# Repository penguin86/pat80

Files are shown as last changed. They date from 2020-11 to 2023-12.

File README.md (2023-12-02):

# Pat80

Pat80 Home Computer Logo

Pat80 Home Computer is an attempt to develop the simplest possible Zilog Z80 based computer in 2021.

## Hardware
Instead of being another single board computer, Pat80 focuses on modularity:
- The Core board contains Z80 CPU, 32k ram, 32k rom, memory and I/O decoding logic
- The Backplane is a stupid I/O bus board with no active components, 1 socket for the Core board and 8 sockets for I/O boards
- Each I/O board must implement tri-state and go to high impedance according to its EN pin to avoid bus contention
- The Power Supply module contains a 7805-based linear power supply capable of delivering 1A @5v for the core and I/O boards

Here is a picture of the early stages of development:

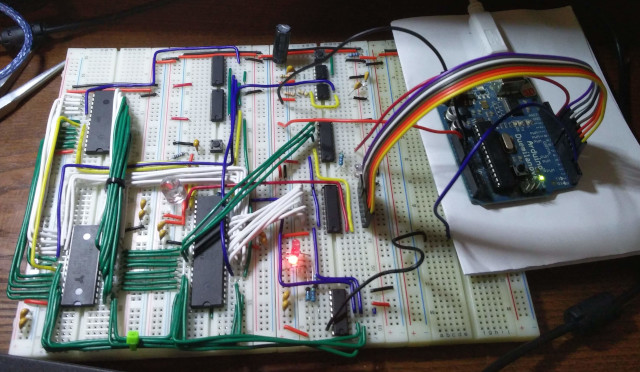
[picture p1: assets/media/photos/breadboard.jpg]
Pat80 Breadboard prototype


### I/O Boards

#### Parallel terminal interface
A parallel terminal based on Arduino is used for development purposes and will be replaced by an UART card.

#### Keyboard controller
Pat80 features a blue-switches mechanical matrix keyboard, seen by the system as a memory area in I/O space. The keyboard doesn't use interrupts and is polled by the OS.

#### Video controller
The monochrome 368x248 pixels video output is software-generated by an ATMega 1284 MCU. The timings are generated by the MCU's 16 bit internal timer and the vertical sync time is used to update the framebuffer.

## Software
The OS is a simple Memory Monitor. It can show memory content in hex and ascii with the typical hex editor tabular view.
Programs can be loaded from the keyboard, writing Z80 opcodes and data in hex. The program can be executed from any ram position and the Memory Monitor can be brought to screen in any moment issuing an INT signal (the Z80 INT pin should be connected to a button with pull-up resistor).
There is an experimental and unfinished quick load function using a python terminal to load a binary file directly to memory and execute it.

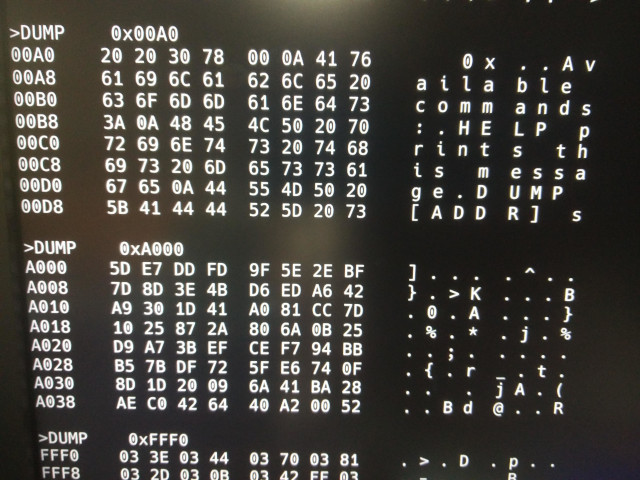
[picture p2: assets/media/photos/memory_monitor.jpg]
Pat80 Memory Monitor


## Emulator
The pat80 memory monitor (the os) can be run in a z80 emulator. This repository contains an emulator as submodule, already set up to run the os.
To try it, head to `pat80-computer/software/z80-assembly/os/Makefile` and run `make run` to build the rom from assembly and start the emulator. You will see some windows showing the emulated computer's memory and register status and the pat80 memory monitor prompt.

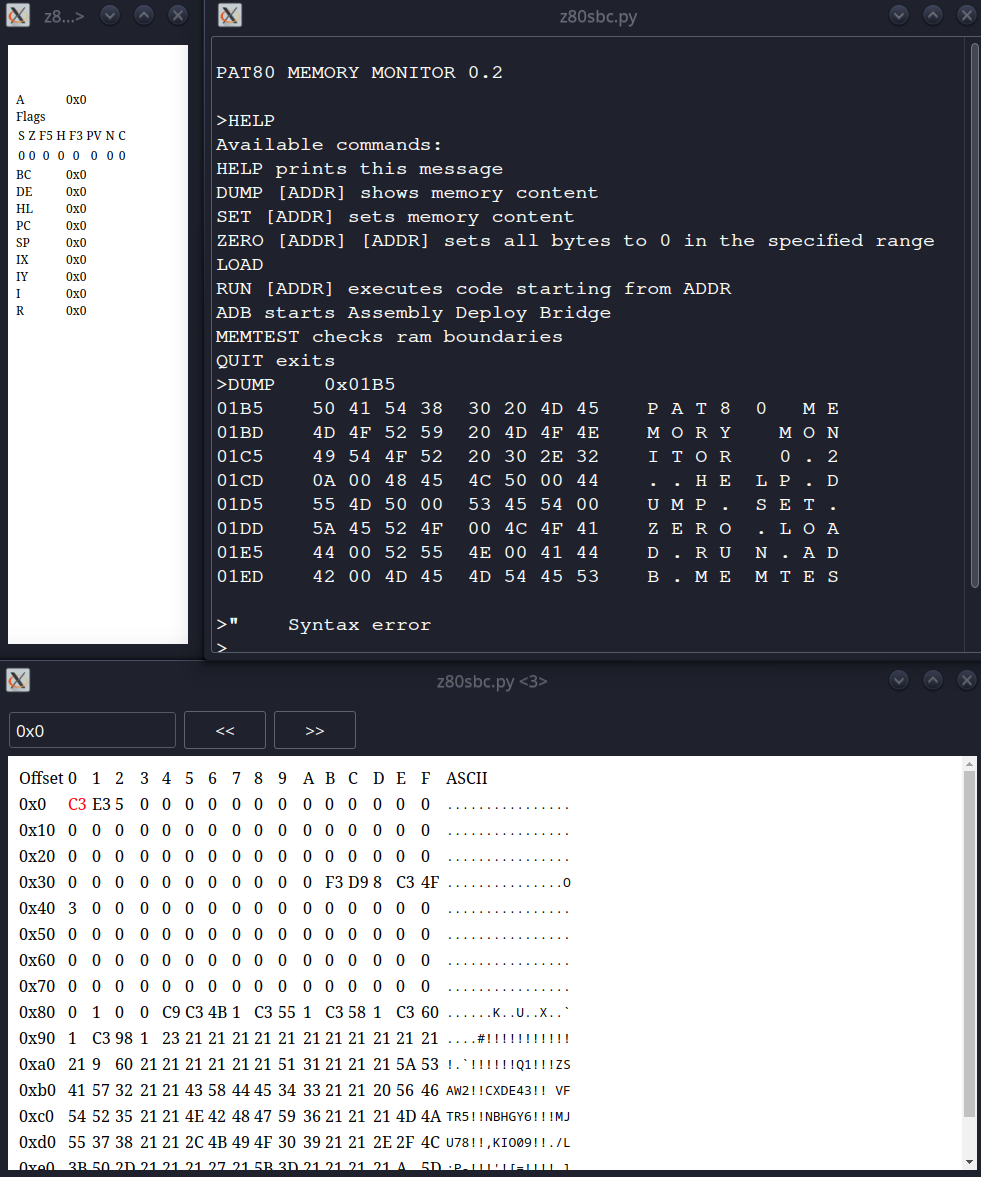
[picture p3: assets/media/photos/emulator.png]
Emulator running Memory Monitor


## Status
The project is heavily work in progress.

### Working
- Core board
- Sound board
- Arduino parallel terminal with its own Python companion script (or any UART terminal)

The only fully working configuration as now is the Core board with two devices hooked to its I/O bus: the Arduino Parallel Terminal (see `pat80-io-devices/parallel-terminal` and `pat80-computer/software/z80-assembly/os/drivers/arduino_terminal.asm`) and the SN76489 sound chip (see `pat80-computer/software/z80-assembly/os/drivers/hd44780.asm`)

### Partially working
The keyboard is only partially tested, as it's not completed.

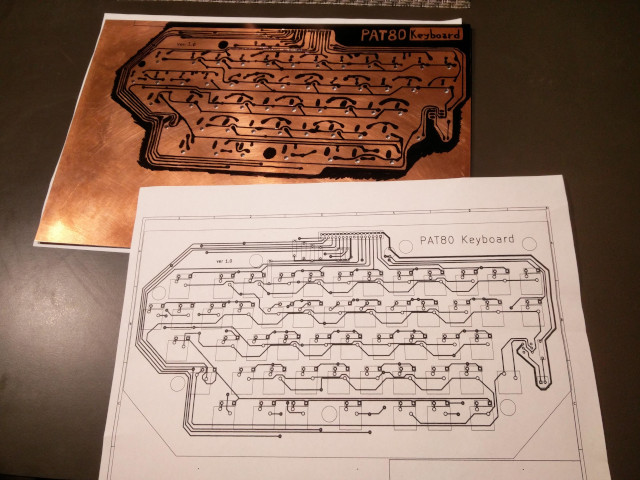
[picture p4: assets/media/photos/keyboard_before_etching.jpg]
Pat80 keyboard pcb


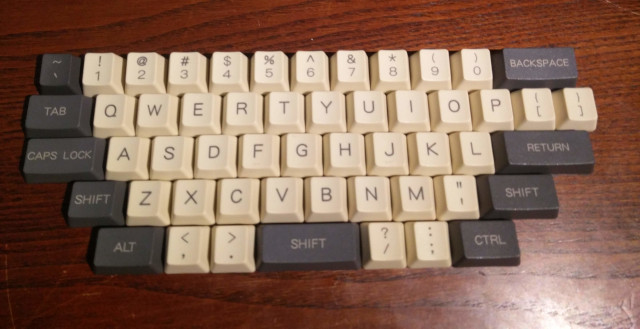
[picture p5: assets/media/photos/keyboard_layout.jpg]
Pat80 keyboard layout


The composite video card is partially working, but has some nasty bugs on text cursor positioning and the graphics mode is not yet implemented (the only way to output graphics ATM is to place the bitmap in the MCU flash and load it to VRAM manually).

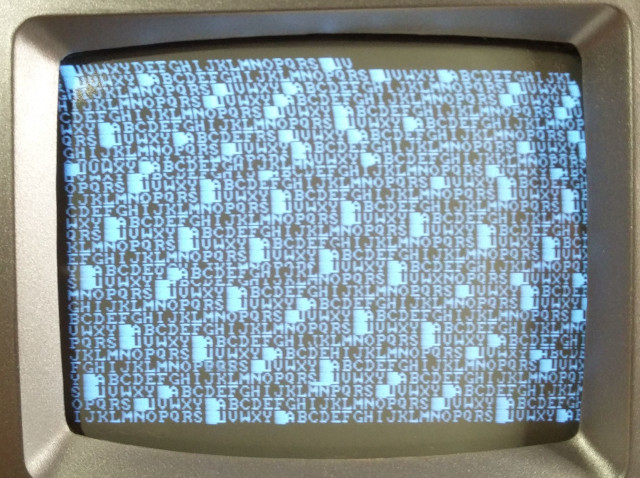
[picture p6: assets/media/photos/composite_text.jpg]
Pat80 composite monitor text mode


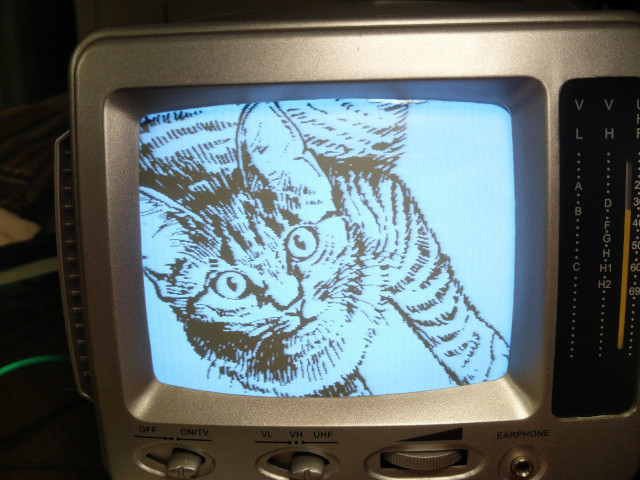
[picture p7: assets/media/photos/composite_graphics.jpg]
Pat80 composite monitor graphics mode


For the moment, better to stick with the Arduino Parallel Terminal.

### Not working
All the rest

## License
All the project is under GPL v3 license

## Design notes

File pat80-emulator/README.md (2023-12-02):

# PAT80 Emulator
This folder contains a submodule (you should fetch it if you need to run the os in an emulator).

Uses cburbridge's Z80 emulator written in python. It opens some windows showing the emulated computer's memory map, the cpu registers state and parallel terminal to interact with the os.

## Usage
To run the os in the emulator, head to `pat80-computer/software/z80-assembly/os/Makefile` and run `make run` to build the rom from assembly and start the emulator.

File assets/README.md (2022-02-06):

# Assets
This folder contains all the media and text assets for presenting Pat80 to the web, print and other media

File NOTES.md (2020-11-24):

# Software utilizzato
Compilatore assembly: z80asm (da repo debian)
Compilatore c: sdcc (da repo debian)
Eeprom flash: minipro (da https://gitlab.com/DavidGriffith/minipro/)
Disegnatore schemi logici: logisim (jar da sourceforge)
    Per usarlo su hdpi: `java -Dsun.java2d.uiScale=2 -jar logisim-generic-2.7.1.jar`
Disegnatore circuiti: fritzing (da repo debian)

# Assembly
## Deploy
### Compilare assembly:
`z80asm -i hd44780_lcd_test_procedure.asm -o rom.bin`
### Portare binario alla dimensione dell eeprom:
`dd if=/dev/zero of=rom.bin bs=1 count=0 seek=8192`
### Scrivere su EEPROM:
`minipro -w rom.bin -p "AT28C64B"`
### Leggere EEPROM:
`minipro -r rom_read.bin -p "AT28C64B"`
## Istruzioni
### Dichiarare una variabile:
Usare EQU per assegnare una posizione di memoria nota (nella RAM) al nome variabile.
```
myVar: EQU 0x800F   ; init variable
ld hl, "A"          ; load value into register
ld (myVar), hl      ; copy value into variable
```
NB: Se il programma si blocca, verificare che la variabile non sia stata dichiarata in una parte non scrivibile della memoria (ROM)
### Accedere ad una variabile
Modificarne il valore (nell'esempio: incrementarla di 1)
```
ld a, (myVar)
inc a
ld (myVar), a
```
Passarne il puntatore ad una funzione:
```
ld bc, myVar
call lcd_print
```
### Segmentation fault
Controllare che non si stia puntando ad un registro con le parentesi:
`ld (ix), a`

# C
## Deploy
### Compilare c:
`sdcc -mz80 test.c`

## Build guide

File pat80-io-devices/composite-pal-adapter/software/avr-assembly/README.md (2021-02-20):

# Atmega Microcontroller
## Build ASM code
`avra filename.asm` (generates *filename.hex*)

## Flash
### Rom
`minipro -w filename.hex -p ATMEGA1284`
### Fuses
Read fuses: `minipro -r -c config -p ATMEGA1284` (`-r -c config` means read configuration (fuses))
Fuses must be written all together, so read the current values, edit the generated file and write it.
The meaning of every bis is in the conf file.
Write fuses: `minipro -w fuses.conf -c config -p ATMEGA1284`

# Generate test images
Using GIMP, Image -> Mode -> Indexed, select 2 colors and Posterize.
Invert the image colors.
Save as .xbm file. Oper with a *text editor*, you will find an array of byte-packed pixels (every byte represents 8 pixels).
Copy and paste on an ASM file.

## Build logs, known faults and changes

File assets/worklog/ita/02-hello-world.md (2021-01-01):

"Roma non è stata costruita in un giorno".
Cominceremo dalle basi. E la base di un computer è proprio il processore.
Il contenuto della scatolina vista nello scorso post è lo Zilog Z80, un processore progettato da Federico Faggin nella prima metà degli anni 70, ed utilizzato poi in innumerevoli computer e console, fino agli anni 90 (eh si, a quei tempi non usciva un processore l'anno...).
Questa CPU è ancora in produzione, sebbene "aggiornata" facendo uso della tecnologia CMOS, molto più efficiente e parca nei consumi. Il modello in mio possesso può essere clockato fino ad 8Mhz, ma se ne trovano modelli fino a 20Mhz! All'epoca una frequenza comune per questo processore era intorno ai 3Mhz (spesso 3,57 per utilizzare un solo cristallo sia per la CPU che per la [generazione di colore per il video](https://en.wikipedia.org/wiki/NTSC#Color_encoding) ).
Oggi, però, la faremo girare moooooolto più lenta.

Da dove cominciare? Per saperlo, bisogna chiederci quale sia il comportamento atteso di un processore. Non è la sede per una spiegazione approfondita, ma basti sapere che il processore (anche i più moderni) non fa altro che eseguire delle istruzioni. Una istruzione è un byte (o se preferite un numero da 0 a 255) che dice al processore cosa fare.
Questo viene ripetuto all'infinito, in un ciclo composto da tre fasi:
- Fetch (ottiene l'istruzione da eseguire dalla memoria)
- Decode (interpreta l'istruzione)
- Execute (la esegue)
Per la nostra prima prova abbiamo bisogno di sapere anche come funziona la memoria.
Ogni memoria (ROM, RAM, Flash...) è composta da una serie di posizioni che possono contenere dei valori. Si accede al contenuto di una posizione in base al suo indirizzo.
Quando il processore viene avviato, non fa altro che cominciare dalla prima posizione di memoria (0), leggere il contenuto (Fetch), capire cosa significa (Decode), eseguirlo (Execute) e passare alla successiva posizione di memoria (1), dove ricomincia da capo.
Ovviamente alcune istruzioni possono modificare questo flusso, ad esempio l'istruzione JP (Jump) dice al processore "Non andare a prendere la prossima posizione di memoria, ma salta alla posizione X".
Per questo motivo noi siamo interessati all'istruzione NOP, (No OPeration): questa istruzione non fa assolutamente nulla. Spreca un ciclo di cpu senza toccare nulla, per cui il processore andrà a cercare l'istruzione successiva nella posizione di memoria successiva.
Ci aspettiamo quindi di vedere i seguenti accessi alla memoria (a destra il valore binario):
0   00000000 00000000
1   00000000 00000001
2   00000000 00000010
3   00000000 00000011
4   00000000 00000100
5   00000000 00000101
etc etc ...

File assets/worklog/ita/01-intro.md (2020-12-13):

È l'inizio degli anni 80. Nelle sale spopolano i Ghostbusters, La Storia Infinita ed E.T. Per i Goonies e Ritorno al futuro bisogna aspettare ancora un po'. La radio suona Girls Just Want To Have Fun di Cyndi Lauper e gli Iron Maiden rilasciano Aces High. Nelle case degli italiani cominciano a comparire i primi Commodore 64, collegati all'onnipresente TV color in sala, magari litigandosi l'unica entrata RF del televisore con un fiammante VHS. Per il NES, invece, bisognerà aspettare ancora un bel po'.

È cominciata la rivoluzione degli Home Computers. I calcolatori non sono più costosissimi ed ingombranti apparecchi riservati ad istituzioni e grosse aziende, ma arrivano nelle case di tutti, in formati compatti e convenienti, a cifre inferiori al mezzo milione di lire. Il software è distribuito prevalentemente su audiocassetta o come listati BASIC da inserire attraverso la tastiera, comprando in edicola i magazines per gli appassionati di home computers.

Solo pochi anni prima sarebbe stato impossibile, per gran parte delle persone, procurarsi un computer, tanto che gli appassionati col pallino dell'elettronica tentavano di costruirsene uno. Gli "homebrew computers" (computer "fatti in casa") sono i veri responsabili dell'inizio di questa rivoluzione, con tutta la letteratura collegata, come i capolavori Build your own Z80 computer di Steve Ciarcia, The Cheap Video cookbook di Don Lancaster o la bibbia di programmazione assembly Programming the Z80 di Rodnay Zaks.

Ho sempre desiderato poter vivere sulla mia pelle la rivoluzione informatica di quegli anni, ma non ne ho avuto la possibilità: non ero ancora nato, e non si può tornare indietro nel tempo.

... oppure sì? Magari con un po' di fantasia! Immaginiamo di essere un appassionato di elettronica desideroso di avere un computer tutto suo. Immaginiamo di riuscire a procurarci un processore. Magari lo Zilog Z80, progettato dall'italiano Federico Faggin e rilasciato nel '76, superiore in molti aspetti al diffusissimo MOS 6502 che dava vita all'Apple II.

Allora, avete voglia di seguirmi in questo viaggio di fantasia che mi porterà a progettare e costruire il:

[LOGO PAT80 COLOR]

L'idea è quella di progettare e costruire un computer da zero, come avrebbe fatto un appassionato a cavallo tra gli anni 70 ed 80. Ispirarmi alle soluzioni esistenti, ma mai copiare e mai inseguire la compatibilità con qualche sistema preesistente. Questo comporterà che io, che non ho mai toccato l'Assembly, scriva un sistema operativo da zero. Probabilità di successo dell'intera impresa: 0%. Ma il calabrone, che non sa di non poter volare, vola lo stesso :"D

Qui Babbo Natale è passato in anticipo, ed ha portato un pacco pieno di... integrati! Ma cosa conterrà la scatolina in cima? Ha 40 pin, ha fatto la storia dell'informatica ma viene prodotto tutt'ora! Molti di voi avranno intuito chi è... ma per gli altri, dovrete aspettare una settimana! 😛

Bio:

Io sono Daniele Verducci, classe '86, professione sviluppatore Android. Conosco Java, Kotlin, linguaggi di alto livello. Per me C o GoLang sono linguaggi di basso livello. L'assembly è aramaico. Elettronicamente, so cos'è un Arduino e ho seguito il corso di elettronica di Andre LaMothe. Sono quasi completamente fuori dalla mia area di competenza, quindi abbiate pazienza se gli aggiornamenti del progetto non saranno frequenti o se rimarrò incagliato, per periodi più o meno lunghi, su qualche problema prima di capire come risolverlo. L'idea è proprio di imparare qualcosa di nuovo, e di farlo insieme!

Sono un appassionato dell'open source, per cui, anche se la macchina non sarà mai in grado di far girare Linux, gli schemi ed i sorgenti del sistema operativo scritto ad hoc saranno rilasciati tutti con licenza GPL v3.

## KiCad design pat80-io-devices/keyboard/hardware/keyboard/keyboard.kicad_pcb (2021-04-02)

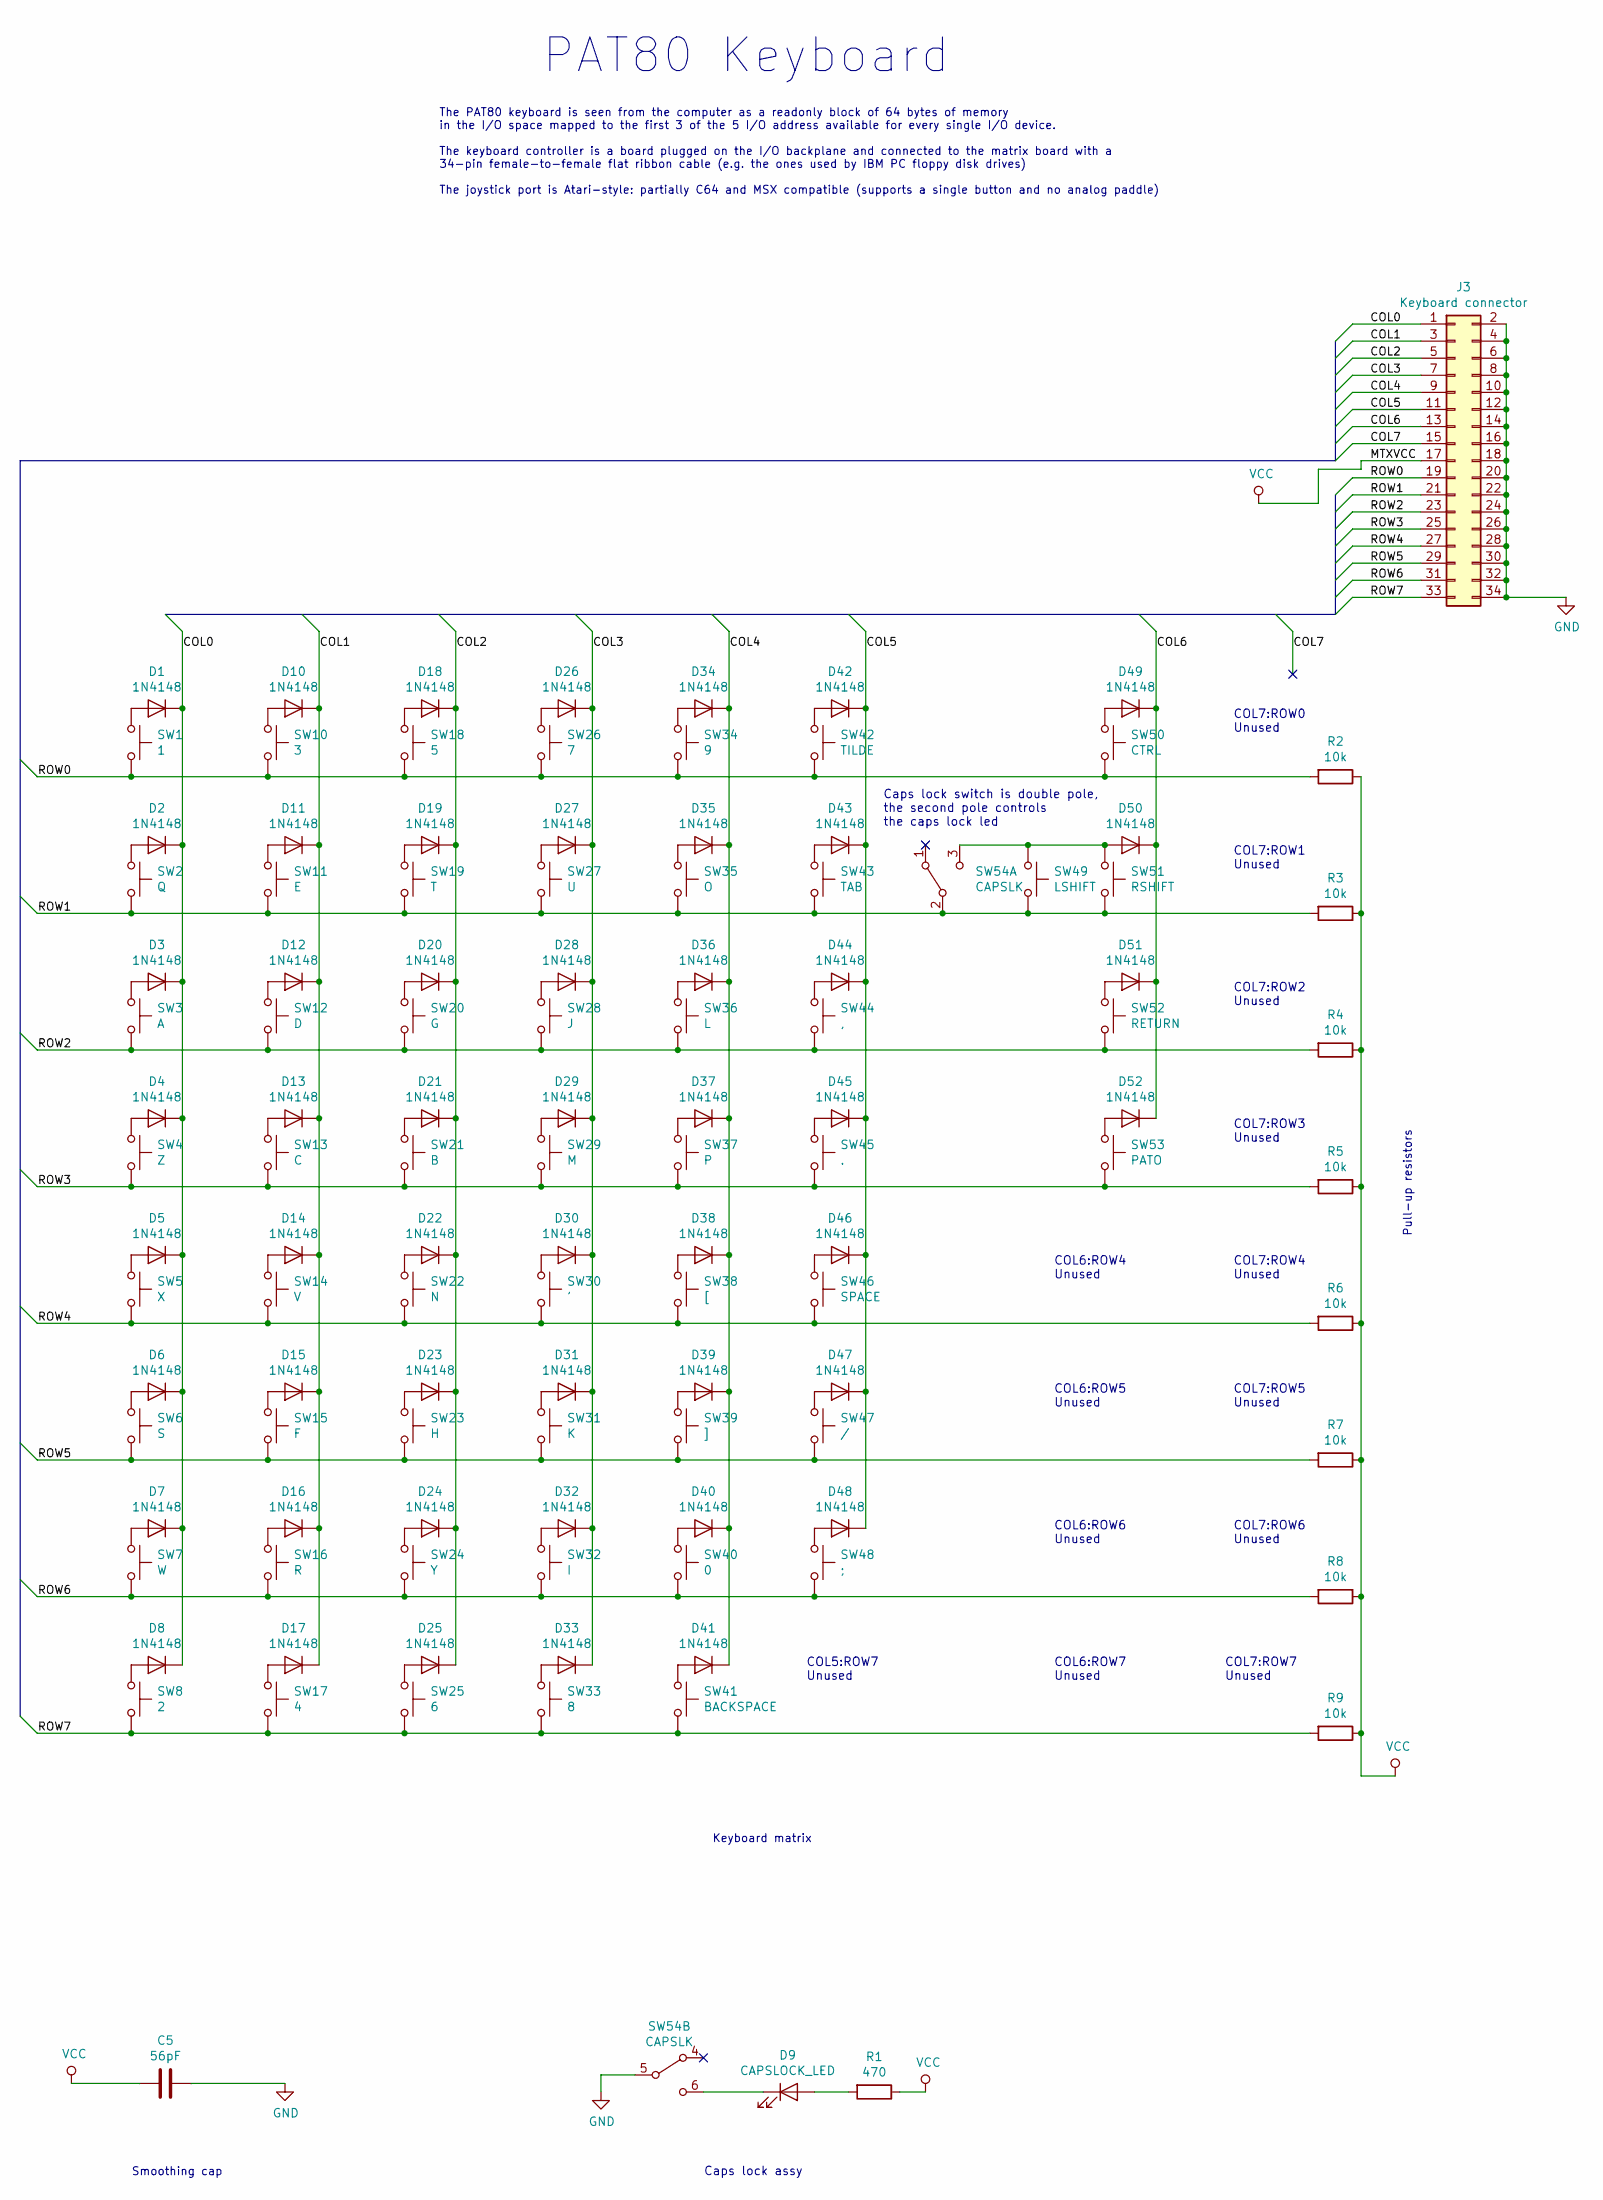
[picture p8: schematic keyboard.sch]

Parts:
C5: 56pF; CP_Radial_Tantal_D6.0mm_P5.00mm
D1, D2, D3, D4, D5, D6, D7, D8, D10, D11, D12, D13, D14, D15, D16, D17, D18, D19, D20, D21, D22, D23, D24, D25, D26, D27, D28, D29, D30, D31, D32, D33, D34, D35, D36, D37, D38, D39, D40, D41, D42, D43, D44, D45, D46, D47, D48, D49, D50, D51, D52: 1N4148; D_DO-41_SOD81_P7.62mm_Horizontal
D9: CAPSLOCK_LED; LED_D5.0mm
J3: Keyboard connector; PinHeader_2x17_P2.54mm_Vertical
R1: 470; R_Axial_DIN0207_L6.3mm_D2.5mm_P7.62mm_Horizontal
R2, R3, R4, R5, R6, R7, R8, R9: 10k; R_Axial_DIN0207_L6.3mm_D2.5mm_P7.62mm_Horizontal
SW1: 1; SW_Cherry_MX1A_1.00u_Plate
SW2: Q; SW_Cherry_MX1A_1.00u_Plate
SW3: A; SW_Cherry_MX1A_1.00u_Plate
SW4: Z; SW_Cherry_MX1A_1.00u_Plate
SW5: X; SW_Cherry_MX1A_1.00u_Plate
SW6: S; SW_Cherry_MX1A_1.00u_Plate
SW7: W; SW_Cherry_MX1A_1.00u_Plate
SW8: 2; SW_Cherry_MX1A_1.00u_Plate
SW10: 3; SW_Cherry_MX1A_1.00u_Plate
SW11: E; SW_Cherry_MX1A_1.00u_Plate
SW12: D; SW_Cherry_MX1A_1.00u_Plate
SW13: C; SW_Cherry_MX1A_1.00u_Plate
SW14: V; SW_Cherry_MX1A_1.00u_Plate
SW15: F; SW_Cherry_MX1A_1.00u_Plate
SW16: R; SW_Cherry_MX1A_1.00u_Plate
SW17: 4; SW_Cherry_MX1A_1.00u_Plate
SW18: 5; SW_Cherry_MX1A_1.00u_Plate
SW19: T; SW_Cherry_MX1A_1.00u_Plate
SW20: G; SW_Cherry_MX1A_1.00u_Plate
SW21: B; SW_Cherry_MX1A_1.00u_Plate
SW22: N; SW_Cherry_MX1A_1.00u_Plate
SW23: H; SW_Cherry_MX1A_1.00u_Plate
SW24: Y; SW_Cherry_MX1A_1.00u_Plate
SW25: 6; SW_Cherry_MX1A_1.00u_Plate
SW26: 7; SW_Cherry_MX1A_1.00u_Plate
SW27: U; SW_Cherry_MX1A_1.00u_Plate
SW28: J; SW_Cherry_MX1A_1.00u_Plate
SW29: M; SW_Cherry_MX1A_1.00u_Plate
SW30: '; SW_Cherry_MX1A_1.00u_Plate
SW31: K; SW_Cherry_MX1A_1.00u_Plate
SW32: I; SW_Cherry_MX1A_1.00u_Plate
SW33: 8; SW_Cherry_MX1A_1.00u_Plate
SW34: 9; SW_Cherry_MX1A_1.00u_Plate
SW35: O; SW_Cherry_MX1A_1.00u_Plate
SW36: L; SW_Cherry_MX1A_1.00u_Plate
SW37: P; SW_Cherry_MX1A_1.00u_Plate
SW38: [; SW_Cherry_MX1A_1.00u_Plate
SW39: ]; SW_Cherry_MX1A_1.00u_Plate
SW40: 0; SW_Cherry_MX1A_1.00u_Plate
SW41: BACKSPACE; SW_Cherry_MX1A_2.00u_Plate
SW42: TILDE; SW_Cherry_MX1A_1.00u_Plate
SW43: TAB; SW_Cherry_MX1A_1.50u_Plate
SW44: ,; SW_Cherry_MX1A_1.00u_Plate
SW45: .; SW_Cherry_MX1A_1.00u_Plate
SW46: SPACE; SW_Cherry_MX1A_2.25u_Plate
SW47: /; SW_Cherry_MX1A_1.00u_Plate
SW48: ;; SW_Cherry_MX1A_1.00u_Plate
SW49: LSHIFT; SW_Cherry_MX1A_1.25u_Plate
SW50: CTRL; SW_Cherry_MX1A_1.50u_Plate
SW51: RSHIFT; SW_Cherry_MX1A_1.75u_Plate
SW52: RETURN; SW_Cherry_MX1A_2.25u_Plate
SW53: PATO; SW_Cherry_MX1A_1.50u_Plate
SW54: CAPSLK; SW_TH_DPDT_Pushbutton_Latched

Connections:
/COL0: D1.1 (K), D2.1 (K), D3.1 (K), D4.1 (K), D5.1 (K), D6.1 (K), D7.1 (K), D8.1 (K), J3.1
/COL1: D10.1 (K), D11.1 (K), D12.1 (K), D13.1 (K), D14.1 (K), D15.1 (K), D16.1 (K), D17.1 (K), J3.3
/COL2: D18.1 (K), D19.1 (K), D20.1 (K), D21.1 (K), D22.1 (K), D23.1 (K), D24.1 (K), D25.1 (K), J3.5
/COL3: D26.1 (K), D27.1 (K), D28.1 (K), D29.1 (K), D30.1 (K), D31.1 (K), D32.1 (K), D33.1 (K), J3.7
/COL4: D34.1 (K), D35.1 (K), D36.1 (K), D37.1 (K), D38.1 (K), D39.1 (K), D40.1 (K), D41.1 (K), J3.9
/COL5: D42.1 (K), D43.1 (K), D44.1 (K), D45.1 (K), D46.1 (K), D47.1 (K), D48.1 (K), J3.11
/COL6: D49.1 (K), D50.1 (K), D51.1 (K), D52.1 (K), J3.13
/COL7: J3.15
/ROW0: J3.19, R2.2, SW1.2, SW10.2, SW18.2, SW26.2, SW34.2, SW42.2, SW50.2
/ROW1: J3.21, R3.2, SW2.2, SW11.2, SW19.2, SW27.2, SW35.2, SW43.2, SW49.2, SW51.2, SW54.2 (B)
/ROW2: J3.23, R4.2, SW3.2, SW12.2, SW20.2, SW28.2, SW36.2, SW44.2, SW52.2
/ROW3: J3.25, R5.2, SW4.2, SW13.2, SW21.2, SW29.2, SW37.2, SW45.2, SW53.2
/ROW4: J3.27, R6.2, SW5.2, SW14.2, SW22.2, SW30.2, SW38.2, SW46.2
/ROW5: J3.29, R7.2, SW6.2, SW15.2, SW23.2, SW31.2, SW39.2, SW47.2
/ROW6: J3.31, R8.2, SW7.2, SW16.2, SW24.2, SW32.2, SW40.2, SW48.2
/ROW7: J3.33, R9.2, SW8.2, SW17.2, SW25.2, SW33.2, SW41.2
GND: C5.1, J3.2, J3.4, J3.6, J3.8, J3.10, J3.12, J3.14, J3.16, J3.18, J3.20, J3.22, J3.24, J3.26, J3.28, J3.30, J3.32, J3.34, SW54.5 (B)
unnamed: D1.2 (A), SW1.1
unnamed: D2.2 (A), SW2.1
unnamed: D3.2 (A), SW3.1
unnamed: D4.2 (A), SW4.1
unnamed: D5.2 (A), SW5.1
unnamed: D6.2 (A), SW6.1
unnamed: D7.2 (A), SW7.1
unnamed: D8.2 (A), SW8.1
unnamed: D9.1 (K), SW54.6 (C)
unnamed: D9.2 (A), R1.2
unnamed: D10.2 (A), SW10.1
unnamed: D11.2 (A), SW11.1
unnamed: D12.2 (A), SW12.1
unnamed: D13.2 (A), SW13.1
unnamed: D14.2 (A), SW14.1
unnamed: D15.2 (A), SW15.1
unnamed: D16.2 (A), SW16.1
unnamed: D17.2 (A), SW17.1
unnamed: D18.2 (A), SW18.1
unnamed: D19.2 (A), SW19.1
unnamed: D20.2 (A), SW20.1
unnamed: D21.2 (A), SW21.1
unnamed: D22.2 (A), SW22.1
unnamed: D23.2 (A), SW23.1
unnamed: D24.2 (A), SW24.1
unnamed: D25.2 (A), SW25.1
unnamed: D26.2 (A), SW26.1
unnamed: D27.2 (A), SW27.1
unnamed: D28.2 (A), SW28.1
unnamed: D29.2 (A), SW29.1
unnamed: D30.2 (A), SW30.1
unnamed: D31.2 (A), SW31.1
unnamed: D32.2 (A), SW32.1
unnamed: D33.2 (A), SW33.1
unnamed: D34.2 (A), SW34.1
unnamed: D35.2 (A), SW35.1
unnamed: D36.2 (A), SW36.1
unnamed: D37.2 (A), SW37.1
unnamed: D38.2 (A), SW38.1
unnamed: D39.2 (A), SW39.1
unnamed: D40.2 (A), SW40.1
unnamed: D41.2 (A), SW41.1
unnamed: D42.2 (A), SW42.1
unnamed: D43.2 (A), SW43.1
unnamed: D44.2 (A), SW44.1
unnamed: D45.2 (A), SW45.1
unnamed: D46.2 (A), SW46.1
unnamed: D47.2 (A), SW47.1
unnamed: D48.2 (A), SW48.1
unnamed: D49.2 (A), SW50.1
unnamed: D50.2 (A), SW49.1, SW51.1, SW54.3 (C)
unnamed: D51.2 (A), SW52.1
unnamed: D52.2 (A), SW53.1
VCC: C5.2, J3.17, R1.1, R2.1, R3.1, R4.1, R5.1, R6.1, R7.1, R8.1, R9.1

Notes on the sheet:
PAT80 Keyboard
The PAT80 keyboard is seen from the computer as a readonly block of 64 bytes of memory in the I/O space mapped to the first 3 of the 5 I/O address available for every single I/O device. The keyboard controller is a board plugged on the I/O backplane and connected to the matrix board with a 34-pin f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
Smoothing cap
COL7:ROW1 Unused
COL7:ROW0 Unused
Keyboard matrix
COL7:ROW7 Unused
COL7:ROW6 Unused
COL7:ROW5 Unused
COL7:ROW2 Unused
COL7:ROW3 Unused
COL7:ROW4 Unused
COL6:ROW7 Unused
COL6:ROW6 Unused
COL6:ROW5 Unused
COL6:ROW4 Unused
COL5:ROW7 Unused
Pull-up resistors
Caps lock assy
Caps lock switch is double pole, the second pole controls the caps lock led

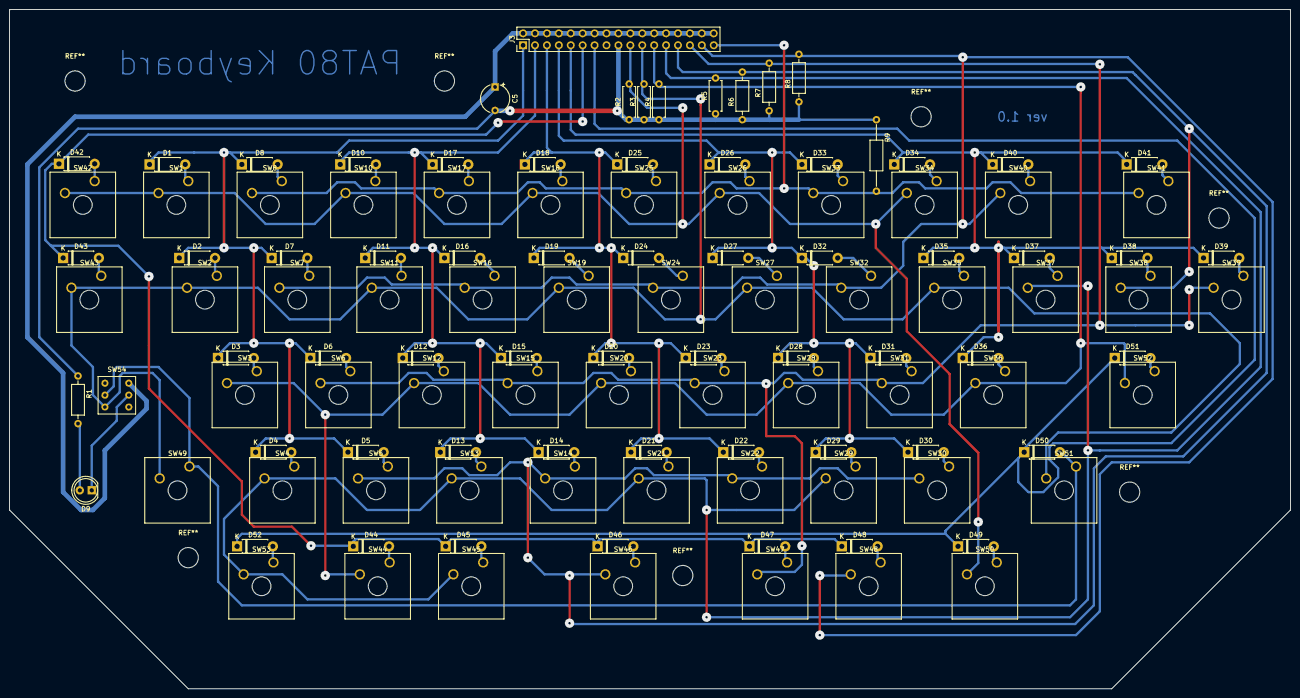
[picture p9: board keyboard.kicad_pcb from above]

Board: 2 copper layers, 273.1 x 144.8 mm, 116 parts (0 on the bottom side), 70 nets.

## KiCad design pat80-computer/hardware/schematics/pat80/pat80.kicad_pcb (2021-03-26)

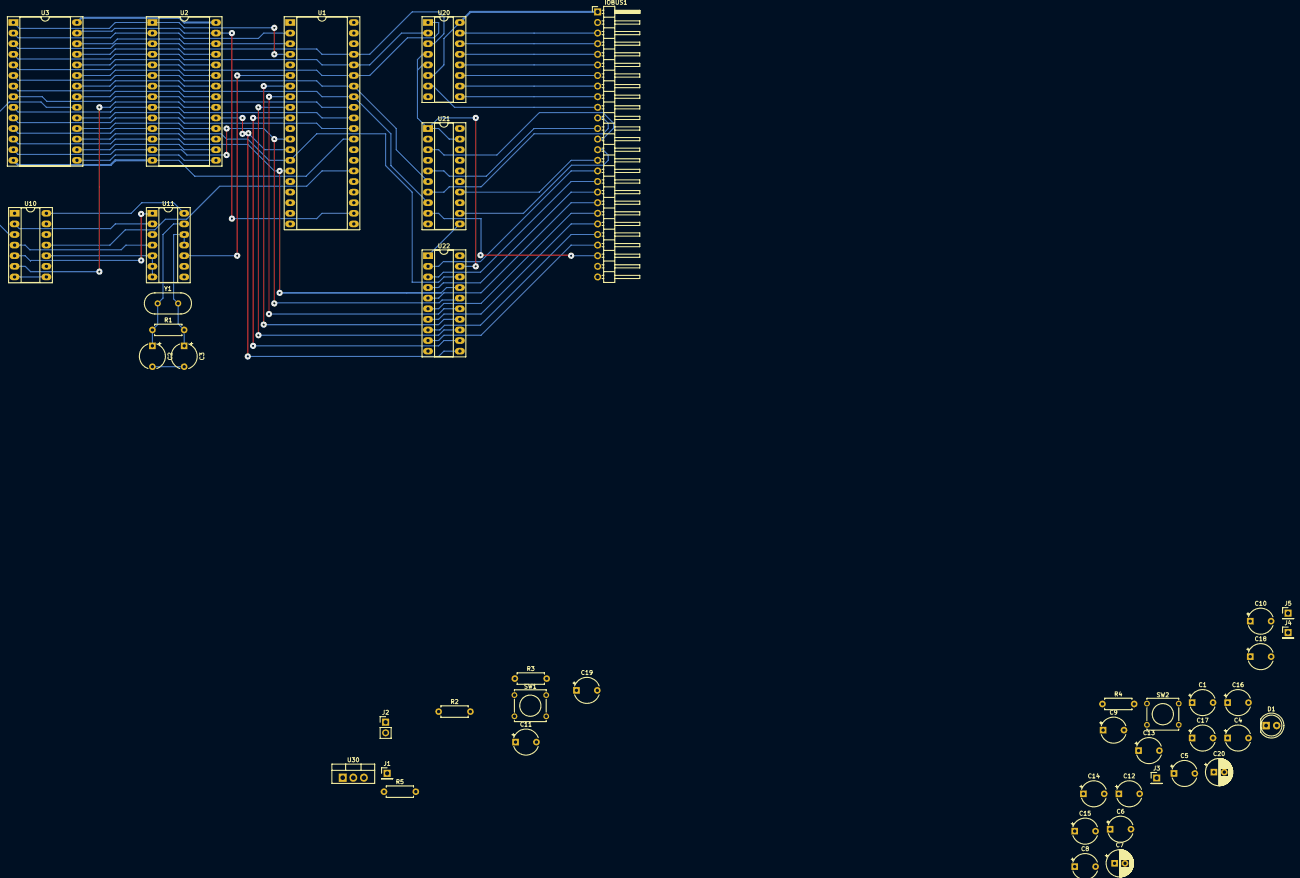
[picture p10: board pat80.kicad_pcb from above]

Board: 2 copper layers, 44 parts (0 on the bottom side), 65 nets.

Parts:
C1, C6: 10uF; CP_Radial_Tantal_D6.0mm_P5.00mm
C2, C3: 30pF; CP_Radial_Tantal_D6.0mm_P5.00mm
C4: 0,22uF; CP_Radial_Tantal_D6.0mm_P5.00mm
C5: 0,1uF; CP_Radial_Tantal_D6.0mm_P5.00mm
C7, C20: 470uF; CP_Radial_D6.3mm_P2.50mm
C8, C11, C13, C14, C16, C18: 100nF; CP_Radial_Tantal_D6.0mm_P5.00mm
C9, C10, C12, C15, C17, C19: 56pF; CP_Radial_Tantal_D6.0mm_P5.00mm
D1: LED; LED_D5.0mm
IOBUS1: IO_bus_conn; PinHeader_1x26_P2.54mm_Horizontal
J1: panel_btn_brk; PinHeader_1x01_P2.54mm_Vertical
J2: Power input; PinHeader_1x02_P2.54mm_Vertical
J3: panel_led_halt; PinHeader_1x01_P2.54mm_Vertical
J4: panel_btn_rst; PinHeader_1x01_P2.54mm_Vertical
J5: nmi; PinHeader_1x01_P2.54mm_Vertical
R1: 3,3M; R_Axial_DIN0207_L6.3mm_D2.5mm_P7.62mm_Horizontal
R2, R3: 10k; R_Axial_DIN0207_L6.3mm_D2.5mm_P7.62mm_Horizontal
R4: 470; R_Axial_DIN0207_L6.3mm_D2.5mm_P7.62mm_Horizontal
R5: 270k; R_Axial_DIN0207_L6.3mm_D2.5mm_P7.62mm_Horizontal
SW1: SW_Push; SW_Tactile_Straight_KSA0Axx1LFTR
SW2: Break; SW_Tactile_Straight_KSA0Axx1LFTR
U1: Z80CPU; DIP-40_W15.24mm_Socket_LongPads
U2: 256k (32k x 8) EEPROM; DIP-28_W15.24mm_Socket_LongPads
U3: 256k (32k x 8) SRAM; DIP-28_W15.24mm_Socket_LongPads
U10: 74HC32; DIP-14_W7.62mm_Socket_LongPads
U11: 74HC04; DIP-14_W7.62mm_Socket_LongPads
U20: 74HC138; DIP-16_W7.62mm_Socket_LongPads
U21: 74HC244; DIP-20_W7.62mm_Socket_LongPads
U22: 74HC245; DIP-20_W7.62mm_Socket_LongPads
U30: LM7805_TO220; TO-220-3_Vertical
Y1: 4Mhz; Crystal_HC18-U_Vertical

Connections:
/A0: U1.30, U2.10, U3.10, U21.17
/A1: U1.31, U2.9, U3.9, U21.15
/A2: U1.32, U2.8, U3.8, U21.13
/A3: U1.33, U2.7, U3.7, U21.8
/A4: U1.34, U2.6, U3.6, U21.6
/A5: U1.35, U2.5, U3.5, U20.1
/A6: U1.36, U2.4, U3.4, U20.2
/A7: U1.37, U2.3, U3.3, U20.3
/A8: U1.38, U2.25, U3.25
/A9: U1.39, U2.24, U3.24
/A10: U1.40, U2.21, U3.21
/A11: U1.1, U2.23, U3.23
/A12: U1.2, U2.2, U3.2
/A13: U1.3, U2.26, U3.26
/A14: U1.4, U2.1, U3.1
/A15: U1.5, U10.5, U11.1
/D0: U1.14, U2.11, U3.11, U22.18
/D1: U1.15, U2.12, U3.12, U22.17
/D2: U1.12, U2.13, U3.13, U22.16
/D3: U1.8, U2.15, U3.15, U22.15
/D4: U1.7, U2.16, U3.16, U22.14
/D5: U1.9, U2.17, U3.17, U22.13
/D6: U1.10, U2.18, U3.18, U22.12
/D7: U1.13, U2.19, U3.19, U22.11
/IOADDR0: IOBUS1.11, U21.7
/IOADDR1: IOBUS1.12, U21.5
/IOADDR2: IOBUS1.13, U21.3
/IOADDR3: IOBUS1.14, U21.12
/IOADDR4: IOBUS1.15, U21.14
/IOD0: IOBUS1.16, U22.2
/IOD1: IOBUS1.17, U22.3
/IOD2: IOBUS1.18, U22.4
/IOD3: IOBUS1.19, U22.5
/IOD4: IOBUS1.20, U22.6
/IOD5: IOBUS1.21, U22.7
/IOD6: IOBUS1.22, U22.8
/IOD7: IOBUS1.23, U22.9
/IOEN0: IOBUS1.3, U20.15
/IOEN1: IOBUS1.4, U20.14
/IOEN2: IOBUS1.5, U20.13
/IOEN3: IOBUS1.6, U20.12
/IOEN4: IOBUS1.7, U20.11
/IOEN5: IOBUS1.8, U20.10
/IOEN6: IOBUS1.9, U20.9
/IOEN7: IOBUS1.10, U20.7
/IORQ: U1.20, U20.4, U20.5, U21.1, U21.19, U22.19
/IOWR: IOBUS1.24, U21.9
/RAMEN: U3.20, U10.3
/RD: U1.21, U2.22, U3.22
/ROMEN: U2.20, U10.6
/WR: U1.22, U2.27, U3.27, U21.11, U22.1
GND: C1.2, C2.2, C3.2, C4.2, C5.2, C6.2, C7.2, C8.1, C9.1, C10.1, C11.1, C12.1, C13.1, C14.1, C15.1, C16.1, C17.1, C18.1, C19.1, C20.2, IOBUS1.2, IOBUS1.25, J2.2, SW1.1, SW2.1, U1.29, U2.14, U3.14, U20.8, U21.10, U22.10, U30.2
unnamed: C1.1, J1.1, R2.1, SW2.2, U1.16
unnamed: C2.1, R1.1, U11.13, Y1.1
unnamed: C3.1, R1.2, U11.11, U11.12, Y1.2
unnamed: C4.1, J2.1, U30.1
unnamed: C6.1, J4.1, R5.2, SW1.2, U10.12, U10.13
unnamed: D1.1, J3.1, U1.18
unnamed: D1.2, R4.1
unnamed: R3.1, U1.17
unnamed: U1.6, U11.10
unnamed: U1.26, U10.11
unnamed: U10.1, U10.4, U11.4
unnamed: U10.2, U11.2
VCC: C5.1, C7.1, C8.2, C9.2, C10.2, C11.2, C12.2, C13.2, C14.2, C15.2, C16.2, C17.2, C18.2, C19.2, C20.1, IOBUS1.1, IOBUS1.26, R2.2, R3.2, R4.2, R5.1, U1.11, U1.24, U1.25, U2.28, U3.28, U20.6, U20.16, U21.20, U22.20, U30.3

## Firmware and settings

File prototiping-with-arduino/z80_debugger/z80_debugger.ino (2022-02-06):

/* ************** DEBUGGER Zilog Z80 ******************
 *
 * This file is part of Pat80 Utils.
 *
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

HARDWARE:

    CORRISPONDENZA PIN CPU -> ARDUINO MEGA 2560

      Arduino   A12  A15  A14  53   51   49   47   45   43   41   39   37   35   33   31   29   27   25   23   20
      Cpu       40   39   38   37   36   35   34   33   32   31   30   29   28   27   26   25   24   23   22   21
                __________________________________________________________________________________________________
               |                                                                                                  |
               |                                                                                                  |
               |_                                                                                                 |
               |_)                                      Zilog Z80                                                 |
               |                                                                                                  |
               |                                                                                                  |
               |__________________________________________________________________________________________________|

      Cpu       1    2    3    4    5    6    7    8    9    10   11   12   13   14   15   16   17   18   19   20
      Arduino   A8   A9   A11  52   50   21   46   44   42   40   38   36   34   32   30   28   26   24   22   A13




    CORRISPONDENZA FUNZIONALE:
      Address bus (A0...A15):     39, 41, 43, 45, 47, 49, 51, 53, A14, A15, A12, A8, A9, A11, 52, 50
      Data bus (D0...D7):         32, 30, 36, 44, 46, 42, 40, 34
      Control bus:
        CLK     21
        INT     28
        NMI     26
        HALT    24
        MREQ    22
        IORQ    A13
        RFSH    35
        RD      20
        WR      23
        BUSACK  25
        WAIT    27
        BUSREQ  29
        RESET   31
        M1      33
      Other
        GND     37, GND
        Vcc     38

*/


const byte MODE_DEBUGGER = 0;
const byte MODE_ROM_EMULATOR = 1;
const byte MODE_ROM_RAM_EMULATOR = 2;

const byte ADDR_BUS[] = {50, 52, A11, A9, A8, A12, A15, A14, 53, 51, 49, 47, 45, 43, 41, 39};
//const byte DATA_BUS[] = {34, 40, 42, 44, 46, 36, 30, 32};
const byte DATA_BUS[] = {3, 4, 5, 6, 7, 8, 9,10};
//const byte CTRL_BUS_RD = 20;
const byte CTRL_BUS_RD = 3;
const byte CTRL_BUS_WR = 23;
const byte CTRL_BUS_BUSACK = 25;
const byte CTRL_BUS_WAIT = 27;
const byte CTRL_BUS_BUSREQ = 29;
const byte CTRL_BUS_RESET = 31;
const byte CTRL_BUS_M1 = 33;
const byte CTRL_BUS_REFRESH = 35;
const byte CTRL_BUS_IORQ = A13;
const byte CTRL_BUS_MREQ = 22;
const byte CTRL_BUS_HALT = 24;
const byte CTRL_BUS_NMI = 26;
//const byte CTRL_BUS_CLK= 21;
const byte CTRL_BUS_CLK= 2;
const byte CTRL_BUS_INT = 28;
const byte PWR_GND = 37;
const byte PWR_VCC = 38;







/* 
 *  SETUP
 *    Mode:
 *      MODE_DEBUGGER = Debugger (stays in high impedance mode listening to inputs/outputs on data, address and control buses)
 *      MODE_ROM_EMULATOR = Emulates rom with the contents of ROM_DATA
 *      MODE_ROM_RAM_EMULATOR = Emulates ram
*/
const byte MODE = MODE_DEBUGGER;

const byte ROM_DATA[] = {0x00, 0x00, 0x00, 0x00, 0xC3, 0x00, 0x00};
//const byte ROM_DATA[] = {0x00, 0x00, 0x00, 0x00, 0x76, 0x00, 0x00};





void setup() {
  Serial.begin(57600);
  Serial.print("Started in mode ");
  switch(MODE) {
    case MODE_DEBUGGER:
    Serial.println("debugger");
    break;    
    case MODE_ROM_EMULATOR:
    Serial.println("rom emulator");
    break;
    case MODE_ROM_RAM_EMULATOR:
    Serial.println("rom/ram emulator");
    break;
  }
  for(int pin=0; pin < 16; pin++) {
    pinMode(ADDR_BUS[pin], INPUT);
  }  
  setDataBusAs(INPUT);
  pinMode(CTRL_BUS_RD, INPUT);
  pinMode(CTRL_BUS_WR, INPUT);
  pinMode(CTRL_BUS_BUSACK, INPUT);
  pinMode(CTRL_BUS_WAIT, INPUT);
  pinMode(CTRL_BUS_BUSREQ, INPUT);
  pinMode(CTRL_BUS_RESET, INPUT);
  pinMode(CTRL_BUS_M1, INPUT);
  pinMode(CTRL_BUS_REFRESH, INPUT);
  pinMode(CTRL_BUS_IORQ, INPUT);
  pinMode(CTRL_BUS_MREQ, INPUT);
  pinMode(CTRL_BUS_HALT, INPUT);
  pinMode(CTRL_BUS_NMI, INPUT);
  pinMode(CTRL_BUS_CLK, INPUT);
  pinMode(CTRL_BUS_INT, INPUT);

  // Set power pins to high impedance, even if we aren't going to read them, to avoid shorts
  pinMode(PWR_GND, INPUT);
  pinMode(PWR_VCC, INPUT);

  attachInterrupt(digitalPinToInterrupt(CTRL_BUS_CLK), onClk, RISING);
  
}

void onClk() {
  setDataBusAs(INPUT);
  
  switch (MODE) {
    case MODE_DEBUGGER:
      debugCycle();
      break;
    case MODE_ROM_EMULATOR:
      emulateRomCycle();
      break;
    default:
      Serial.println("Unimplemented mode");
  }
}

void loop() {}

void debugCycle() {
  if (!digitalRead(CTRL_BUS_RD) || !digitalRead(CTRL_BUS_WR)) { //RD e WR are active-low
    unsigned int address = getAddress();  
    unsigned int data = getData();    
  
    char output[30] = {};
    sprintf(output, "%04x  %c%c  %02x  %s", address, digitalRead(CTRL_BUS_RD) ? '-' : 'r', digitalRead(CTRL_BUS_WR) ? '-' : 'w', data, digitalRead(CTRL_BUS_RESET) ? "" : "reset");
    Serial.println(output);
  }
}

void emulateRomCycle() {
  if (!digitalRead(CTRL_BUS_RD)) {  //RD e WR are active-low
    unsigned int addr = getAddress();
    if (addr < sizeof(ROM_DATA)) {
      unsigned int data = ROM_DATA[addr];
      writeByteToDataBus(data);
      
      char output[30] = {};
      sprintf(output, "%04x  r-  %02x Emu ROM read", addr, data);
      Serial.println(output);
    }
  }
  if (!digitalRead(CTRL_BUS_WR)) {
    debugCycle();    
  }
}

unsigned int getAddress() {
  unsigned int address = 0;
    for(int pin=0; pin < 16; pin++) {
      byte b = digitalRead(ADDR_BUS[pin]) ? 1 : 0;
      //Serial.print(b);
      address = (address << 1) + b;   // Shifta di 1 e aggiunge il bit corrente. Serve per ricostruire il numero da binario
    }  
    return address;
}

unsigned int getData() {
  unsigned int data = 0;
    for(int pin=0; pin < 8; pin++) {
      byte b = digitalRead(DATA_BUS[pin]) ? 1 : 0;
      //Serial.print(b);
      data = (data << 1) + b;   // Shifta di 1 e aggiunge il bit corrente. Serve per ricostruire il numero da binario
    }
    return data;
}

void setDataBusAs(byte mode){
  for(int pin=0; pin < 8; pin++) {
    pinMode(DATA_BUS[pin], mode);
  }  
}

void writeByteToDataBus(byte j) {
  setDataBusAs(OUTPUT);
  for (int n=0; n<8; n++)
  {
    if((0x01&j) < 0x01)
    {
      digitalWrite(DATA_BUS[n],LOW);
    } else {
      digitalWrite(DATA_BUS[n],HIGH);
    }
    j>>=1;
  }
}

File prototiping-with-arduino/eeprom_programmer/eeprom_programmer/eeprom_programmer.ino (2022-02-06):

/* ************** EEPROM PROGRAMMER ******************
 * This file is part of Pat80 Utils.
 *
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

NOTE: This is not working and I'm not sure if it will be fixed or removed,
as I'm actually using an USB programmer.


HARDWARE:

    CORRISPONDENZA PIN EEPROM Atmel AT28C64B  -> ARDUINO MEGA 2560
    (Compatibile con eeprom fino a 16 bit di address bus. In caso di altre eeprom collegare secondo datasheet)
    NB: Nel caso della eeprom da 8k, ci sono solo 12 address bus, quindi gli altri 4 pin provenienti dall'Arduino
    vengono lasciati disconnessi

      Arduino   VCC  11        38   40   44   10   42   12    9    8    7    6    5
      Eeprom    28   27   26   25   24   23   22   21   20   19   18   17   16   15
                ____________________________________________________________________
               |                                                                    |
               |                                                                    |
               |_                                                                   |
               |_)                         Atmel AT28C64B                           |
               |                                                                    |
               |                                                                    |
               |____________________________________________________________________|
               
      Eeprom    1    2    3    4    5    6    7    8    9    10   11   12   13   14
      Arduino       46    36  34   32   30   28   26   24    22    2    3    4   GND




    CORRISPONDENZA FUNZIONALE:
    
      Address bus (A0...A15):     22, 24, 26, 28, 30, 32, 34, 36, 38, 40, 42, 44, 46, 48, 50, 52
      
      Data bus (D0...D7):         2, 3, 4, 5, 6, 7, 8, 9
  
      Control bus:
        /OE     10
        /WE     11
        /CE     12

*/

const byte ROM_DATA[] = {0x76, 0x00, 0x00, 0x00, 0x76, 0x00, 0x00};


const byte ADDR_BUS[] = {52, 50, 48, 46, 44, 42, 40, 38, 36, 34, 32, 30, 28, 26, 24, 22};
const byte DATA_BUS[] = {9, 8, 7, 6, 5, 4, 3, 2};
const byte CTRL_BUS_OE = 10;
const byte CTRL_BUS_WE = 11;
const byte CTRL_BUS_CE = 12;

void setup() {
  Serial.begin(57600);
  for(int pin=0; pin < 16; pin++) {
    pinMode(ADDR_BUS[pin], OUTPUT);
  }
  setDataBusAs(INPUT);
  pinMode(CTRL_BUS_OE, OUTPUT);
  pinMode(CTRL_BUS_WE, OUTPUT);
  pinMode(CTRL_BUS_CE, OUTPUT);
  digitalWrite(CTRL_BUS_OE, HIGH);  //Active low
  digitalWrite(CTRL_BUS_WE, HIGH);  //Active low
  digitalWrite(CTRL_BUS_CE, HIGH);  //Active low

  delay(1000);
  
  //readRom(8192);
  writeRom();
  verifyRom();
}

void writeRom() {
  digitalWrite(CTRL_BUS_OE, HIGH);
  setDataBusAs(OUTPUT);
  Serial.print("Starting to write ROM... ");
  for (int i=0; i<sizeof(ROM_DATA); i++) {
    writeIntToAddressBus(i);
    delayMicroseconds(5); // Address hold time (tAH)
    digitalWrite(CTRL_BUS_CE, LOW);
    digitalWrite(CTRL_BUS_WE, LOW);
    writeByteToDataBus(ROM_DATA[i]);
    delayMicroseconds(5); // Data setup time (tDS)
    digitalWrite(CTRL_BUS_WE, HIGH);
    digitalWrite(CTRL_BUS_CE, HIGH);  //Active low
    delayMicroseconds(5); // Data hold time (tDH)
  }
  setDataBusAs(INPUT);
  Serial.println("Done.");
}

void verifyRom() {
  Serial.print("Starting to verify ROM... ");
  digitalWrite(CTRL_BUS_WE, HIGH);  //Active low
  char output[50] = {};
  for (int i=0; i<sizeof(ROM_DATA); i++) {
    writeIntToAddressBus(i);
    delayMicroseconds(5);
    digitalWrite(CTRL_BUS_OE, LOW);  //Active low
    digitalWrite(CTRL_BUS_CE, LOW);  //Active low
    delayMicroseconds(5);
    byte readData = getData();
    if(readData != ROM_DATA[i]) {
      sprintf(output, "Error at addr %04x: expected %02x, found %02x", i, ROM_DATA[i], readData);
      Serial.println(output);
    }
    
    while(true){}
    digitalWrite(CTRL_BUS_OE, HIGH);  //Active low
    digitalWrite(CTRL_BUS_CE, HIGH);  //Active low
    delayMicroseconds(5);
  }
  Serial.println("Done.");
}

void readRom(int bytes) {
  digitalWrite(CTRL_BUS_WE, HIGH);  //Active low
  char output[50] = {};
  for (int i=0; i<bytes; i++) {
    writeIntToAddressBus(i);
    delayMicroseconds(5);
    digitalWrite(CTRL_BUS_OE, LOW);  //Active low
    digitalWrite(CTRL_BUS_CE, LOW);  //Active low
    delayMicroseconds(5);
    byte readData = getData();
    sprintf(output, "0x%02x ", readData);
    Serial.print(output);
    digitalWrite(CTRL_BUS_OE, HIGH);  //Active low
    digitalWrite(CTRL_BUS_CE, HIGH);  //Active low
    delayMicroseconds(5);
  }
  Serial.println("Done.");
}

unsigned int getData() {
  setDataBusAs(INPUT);
  unsigned int data = 0;
    for(int pin=0; pin < 8; pin++) {
      byte b = digitalRead(DATA_BUS[pin]) ? 1 : 0;
      data = (data << 1) + b;   // Shifta di 1 e aggiunge il bit corrente. Serve per ricostruire il numero da binario
    }
    return data;
}

void setDataBusAs(byte mode){
  for(int pin=0; pin < 8; pin++) {
    pinMode(DATA_BUS[pin], mode);
  }  
}

void writeByteToDataBus(byte j) {
  setDataBusAs(OUTPUT);
  for (int n=0; n<8; n++)
  {
    if((0x01&j) < 0x01)
    {
      digitalWrite(DATA_BUS[n],LOW);
    } else {
      digitalWrite(DATA_BUS[n],HIGH);
    }
    j>>=1;
  }
}


void writeIntToAddressBus(int j) {
  for (int n=0; n<16; n++)
  {
    if((0x01&j) < 0x01)
    {
      digitalWrite(ADDR_BUS[n],LOW);
    } else {
      digitalWrite(ADDR_BUS[n],HIGH);
    }
    j>>=1;
  }
}

void loop() {}

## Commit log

2020-11-01 Added IO address decoding. Lorem ipsum demo (without sorting LCD cursor addressing problems).
    [main.asm]
2020-11-01 WIP keyboard driver
2020-11-19 WIP Arduino VGA adapter
2020-11-22 Working echo test for arduino terminal
2020-11-22 Added Arduino terminal, moved drivers config variables to each driver asm file
2020-11-23 Implemented read char and readline in arduino terminal driver
2020-11-24 Code refactoring, working char read and print, working line print, not working line read
    [main.asm]
2020-11-29 Trying optimizing terminal to stay under 600nS per clock cycle (not working ATM)
    [arduino_terminal.ino]
2020-11-29 Maybe found bug in arduino terminal
    [arduino_terminal.ino]
2020-12-02 SN76489 sound test with Arduino
2020-12-06 NS76489 digital pin order is fucking inverted! D0 is the MSB, D7 the LSB.
2020-12-15 Python terminal emu not working with Python versions less than 3
    [terminal_emulator.py]
2020-12-21 Monitor DUMP prints bytes with the standard hex editor layout
2020-12-26 Testing sdcard initialization with Arduino
2020-12-29 Trying to obtain fixed position system calls. Not working ATM
    [main.asm]
2021-01-02 WIP immediate return to monitor via interrupt
2021-01-02 Reorganized folders, added pal-adapter io device folder
    [main.obj]
2021-01-02 pal-adapter: fuses config and readme
2021-01-02 First working image with a lot of jitter
    [main.asm]
2021-01-03 Interrupt brings up Monitor: working, but calling "run" leaves garbage in the SP
2021-01-03 New test pattern, still hsync issues
    [main.asm]
2021-01-07 Read framebuffer from mc's memory
2021-01-08 Scrambled image due to inverted bit order in every of the 52 line byte chunks
    [main.asm]
2021-01-08 Working stable non-interlaced image of cat read from rom into ram framebuffer
2021-01-09 Documented idea of interrupt-driven video generation
2021-01-10 Not working implementation of timer-driven video signal generation
    [main.asm]
2021-01-10 Not working implementation of timer-driven video signal generation 2
    [main.asm]
2021-01-13 Using official mc device definition
2021-01-16 Working timer1, but wrong timings
    [main.asm]
2021-01-17 Fixed halved number of sync pulses
    [main.asm]
2021-01-17 Temporary fix for first short sync timer after image firing in advance
    [main.asm]
2021-01-19 Copying data bus to framebuffer memory, but ignoring clock signal
2021-02-03 Started implementing PS/2 Keyboard driver
2021-02-03 WIP PS/2 keyboard driver
2021-02-07 Reading ps/2 keyboard, but somehow, keycodes are decremented by 1
    [ps2_modeset_2_to_ascii.ods]
2021-02-09 WIP PS/2 Keyboard
    [ps2_modeset_2_to_ascii.ods]
2021-02-20 Straight, but unstable image. Some unwanted spaces during vertical sync
    [main.asm, video_generator.asm]
2021-02-22 Working carriage return
2021-02-28 Reduced problem on char draw
    [main.asm]
2021-03-05 WIP UART Rx simulation with Logisim
2021-03-06 Working UART simulation without rx clock sync
2021-03-06 UART: Thinking how to delay sampling to mid clock
2021-03-15 WIP UART sampling at mid clock
2021-03-15 WIP Mainboard schematics: added CPU, RAM, ROM, Addr and data bus.
    TODO: Fix external dependency
    [pat80.kicad_pcb, pat80.sch]
2021-03-15 Removed symbol using third party library
    [pat80.sch]
2021-03-15 Reset circuit
    [blank_expansion_board.fzz, pat80.sch, pato.fzz]
2021-03-17 WIP Schematics
    [pat80.sch]
2021-03-19 Memory decoding, WIP IO decoding
    [pat80.sch]
2021-03-20 Almost finished transcribing mainboard schematics
    [pat80.sch]
2021-03-20 Schematic complete, commit before assigning footprints
    [pat80.sch]
2021-03-20 Schematics: assigned footprints, created ratsnest
    [pat80.sch]
2021-03-21 Connector description
    [pat80.sch]
2021-03-21 WIP Keyboard schematics (too much keys)
    [keyboard.kicad_pcb, keyboard.sch]
2021-03-22 WIP Keyboard schematics
    [keyboard.sch]
2021-03-26 WIP mainboard routing
    [pat80.kicad_pcb]
2021-03-26 Completed keyboard schematics
    [keyboard.sch]
2021-03-27 Final keyboard schematics with joystick port
    [keyboard.sch]
2021-03-27 Assigning footprints
    [keyboard.sch]
2021-03-27 Split keyboard into two different schematics: kb controller and kb assembly. Started routing keyboard pcb.
    [keyboard.kicad_pcb, keyboard.sch]
2021-03-27 Fine-positioned caps lock switch
    [keyboard.kicad_pcb, keyboard.sch]
2021-03-27 Distanced keys to avoid interference
    [keyboard.kicad_pcb]
2021-03-28 WIP routing keyboard
    [keyboard.kicad_pcb, keyboard.sch]
2021-03-30 Completed routing keyboard PCB
    [keyboard.kicad_pcb]
2021-03-30 Keyboard PCB: edge cuts and mounting holes
    [keyboard.kicad_pcb]
2021-04-02 Fixed caps lock footprint error
    [keyboard.kicad_pcb]
2021-07-11 Ready for github publishing
    [blank_expansion_board.fzz, pato.fzz]

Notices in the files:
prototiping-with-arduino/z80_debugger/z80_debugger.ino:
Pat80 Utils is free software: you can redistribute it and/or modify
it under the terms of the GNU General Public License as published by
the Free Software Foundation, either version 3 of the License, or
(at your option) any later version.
